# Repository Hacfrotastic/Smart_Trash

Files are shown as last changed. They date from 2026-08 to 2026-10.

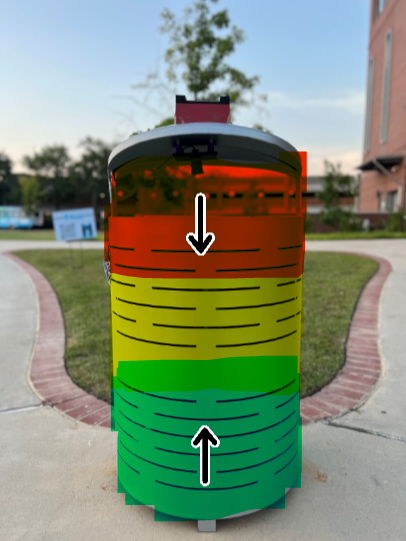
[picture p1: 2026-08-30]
Images/ST_Trash_LEVELS.png

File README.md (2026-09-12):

# Smart_Trash

## Intro

Smart trash is autonomous monitoring system bult to measure the levels in a trash cans. Once measurements are taken the device then sends them to grafana where they can be remotely monitored. This project was started to help give facilities and matinence more insight into how trash is disposed of on their campus. With levels constantly being monitered staff can see when each trash can need to be changed rather then relying on a scheduele.

## Latest Versions
 Code   - 
 Model  - *Fusion will not let me export rn.
 PCB    - 

## Previous contributers
- Hacfrotastic 
- Cameron Cuningham <- Spell check...

## Next Steps - We got this [on] the bag

April 15th 2026 we deployed the device in a trash can that does not get much traffic. On this day (August 30th 2026) it is still sending data with 6% battery life remaining (and 3.67 V for those interested). For a largew duration of the sensors deployement it was reading 85% full. I suspect these reading to be false and instead be the trash bag fluffed up by the air. I thought I solved this issue by adding a "bag flag" but apparently not....

 Additionally the reading value recently dropped to 0. I assume this is just a result of the battery dying

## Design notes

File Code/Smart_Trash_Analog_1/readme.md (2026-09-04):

# Smart_Trash Analog 

This is where it all started (kinda), so let's run through how it works.

## Setup()

Here we do 3 things. 
- set up our variable
- Establish some particle functions (see more in function section)
- configure sleep settings (config.mode)

## Loop()

Meat and potatoes time!!!

This is your typical analog readings code. 
- Get 10 readings from the ultrasonic sensor
    + We are working with 3.3V logic
    + The Borons ADC is 4096 bits
    + This Maxbotic sensors conversion formula is  3.2 cm per mV
    My code looks a little wrong to me, I believe in the code I'm using just volts in the formula (Needs Testing)
- Average readings 
- Calculate status based on reading
    + This started out as a discrete status, some may even say it was quantized. 1=Empty 2=halfway 3=full that is what you see on the first line of each if statement commented out.
    + Eventually we moved status to be a percent calculation with the formula in the second line. The formula takes the reading and divides it by the known max of the trashcan (70cm) while multiplying that number by 100 so it mimics a percent. Lastly subracting that number from 100 since the distance reading is the inverse of how full the trash can is. Cool right. 
- If status changes publish the status
    + The snprintf statement make the string; Particle.publish then sends it.

## Functions 
Lets go ahead and describe what each function does

### Debug 

 Expected input : Leave blank, input does not matter
 This runs the basic reading cycle and returns what ever status was reported

 ### Bedtime

 Expected input : Leave blank, input does not matter
 Forces the sensor to go to bed. The sleep time is hardcoded and set by the config.mode statement in setup()

 ### Battery_Rep
 
 Expected input : Leave blank, input does not matter
 This ones a little weird and a relic of me not knowiung how to do some things, but I'll leve it how it is so the reader can judge me. 
 First the board gets the percent of battery charge (ex. 100 -> 100% -> full charge). Then it reads the batteries voltage. Both of these readings are read using the Particle Borons built in "FuelGauge" functions that I have instatiated at the top of the code file. 
 To return both of the numbers in the same function, SOMONE had the "brilliant idea" of shifting the battery percent up by 1000 and adding the voltage to that. Example, battery percent = 83 Voltage = 3.7 makes the reported value 83003.7. Weird but it kinda works... 
 However,
  A) having two seperate published just seems better 
  B) THE INT CUTS THE DECIMAL OFF!!! I mean what the point of that kind of reading anyway. 3.7 drops to 3, so when you have full charge ~3.9V on my battery the function reads 4 and when you get low, hell even DEAD, ~3.5 it drops it to, you'll never guess 3!!!!!
  (Or new me is wrong and old me is better at coding, which is possible. Test it and find out)

  ### Function Graveyard

  There are some commented out functions I put in there with hipes of expanding the code to store GPS cords. ,but I never around to it. I'll leave them in there though to inspire.

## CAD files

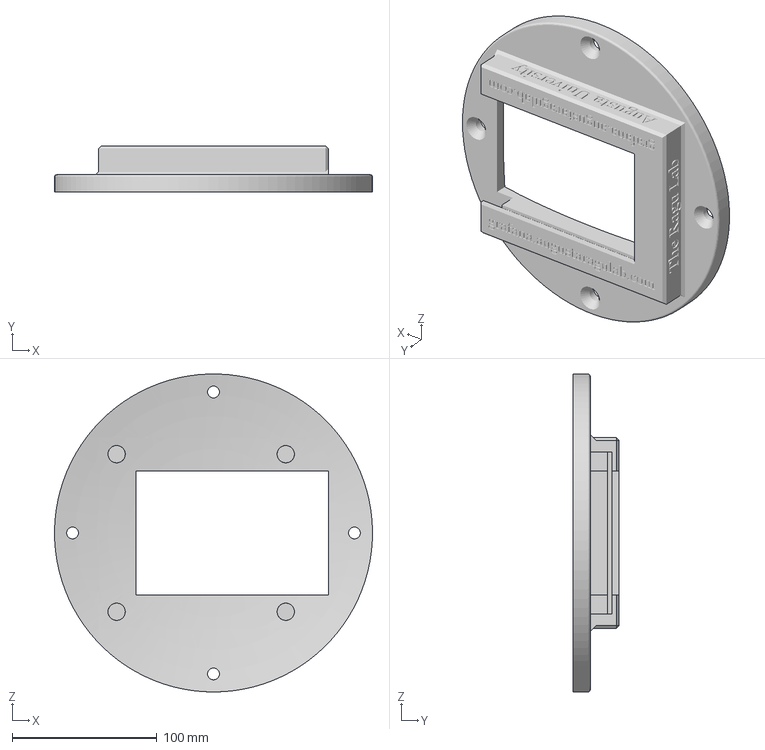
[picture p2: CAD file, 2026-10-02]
Design/CAD_Files/New_trash_Lid.3mf
220.0 x 32.1 x 219.9 mm

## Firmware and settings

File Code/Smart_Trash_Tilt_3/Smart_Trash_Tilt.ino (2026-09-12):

// This #include statement was automatically added by the Particle IDE

// Include Particle Device OS APIs
#include "Particle.h"
char buf[255];
int aReading;
int status; 
int nowDis;             //distance for avg
int stateOfCharge;      //for fuel gauge battery monitoring 
int batteryVoltage;     //^^
int report;
FuelGauge fuel;         
int readingPin = A0;    //Analog pin for reading distance
int powerPin = D13;     // pin for powering sensor (poor mans MosFet)
int tilt = A1;          //For tracking when the bag gets changed
bool isAwake;           //reports if the sensor is awake (currently it wakes up and stays after the noon report)
int numSamp = 25;       //Number of times the sensor will raje a reading before averaging
float cmDis = 0;        //
String myDev;
//Required constructor to remember device name.

// Let Device OS manage the connection to the Particle Cloud
SYSTEM_MODE(AUTOMATIC);

// Show system, cloud connectivity, and application logs over USB
// View logs with CLI using 'particle serial monitor --follow'
SerialLogHandler logHandler(LOG_LEVEL_INFO);
SystemSleepConfiguration config;

int EEPUT(String x)             // Functions for storing the name of the device in EEPROM
{
    //Get rid of spaces in the string
    for(int ii = 0; ii<x.length(); ii++)
    {
        if(x[ii]== ' ')
        {
            x[ii] = '_';
        }
    }
    //put the string in EEPROM
    EEPROM.put(1, x.length());
    for(int ii = 0; ii < x.length(); ii++)
    {
        EEPROM.put((ii + 2),x[ii]);
    }
    System.reset();
    return 1;
}

char* EEGET()                //Gets Device name from EEPROM
{
    if(EEPROM.read(1) != 0xFFFF) //if the memory is not empty, read it
    {
        
        int bytes2Read = EEPROM.read(1);
        static char dev_Name[100] = " "; 
        for(int ii = 0; ii<bytes2Read; ii++)
        {
         dev_Name[ii] = EEPROM.read((ii + 2));
        }
        return dev_Name; 
    }
    
    return "ERROR";
}

void SetBagFlag(bool state)
{
    if (state == 1)
    {
        EEPROM.put(201, "1");    //Flag on
    }
    else if(state == 0)
    {
        EEPROM.put(201,"0");     //Flag off
    }
    delay(1000);                 //Delay because I do not trust things 
    System.reset();              //Reset it for EEPROM to register
}

byte GetBoolFlag()
{
    byte state = EEPROM.read(201);
    return state;
}
// setup() runs once, when the device is first turned on
void setup() 
{
    Time.zone(-4);
    myDev = EEGET(); 
    while(!Particle.connected() || myDev == "ERROR") //Wait for board to connect or recieve name.
    {
        //wait for boron board to connect to cell
    }
    pinMode(readingPin, INPUT);
    pinMode(powerPin, OUTPUT);
    Particle.variable("Sensor Awake", isAwake);
    Particle.function("Measure Percent Full",debug);
    config.mode(SystemSleepMode::ULTRA_LOW_POWER).duration(60min); 
    Particle.function("Bedtime",bedtime);
    Particle.function("Set Name", EEPUT);
    Serial.begin(9600);
    
    //Setup required to retain name.
}

// loop() runs over and over again, as quickly as it can execute.
void loop() 
{
 /*
 Problem: The sensor sometimes reported 0 as a measurement when there were items in the trash can
 
 Fix:     I added a for loop that loops 2 times if and only if the reading reported is 0, this way
          the ultrasonic will double check all reports of 0s but can still publish 0 if the can is 
          actually empty 
          Also upped the amount of samples taken (10 -> 50)
 */
    
    //give a five minute delay so the sensor can retrieve its name 
    
 
  digitalWrite(powerPin, HIGH);  //turn on sensor through GPIO pin so it is not drainging the battery
  delay(30000);
  float avg;
  for(int ii=0; ii<numSamp ; ii++)
  {
     int aReading = analogRead(readingPin);
     float volts = (aReading*3.3)/4096;
     float cmDis = volts/0.0032;
     avg += cmDis; 
     Serial.print("Cm: ");
     Serial.print(cmDis);
     Serial.print("Avg: ");
     Serial.println(avg);
     delay(1000);
     
  }
  avg = avg/numSamp;
  int status = 100 - (((avg-15)/70)*100);  
  //filter status
  if (status > 100)
  {
      status = 100;
  }
  else if (status < 0)
  {
      status = 0;
  }
  
  Serial.println(status);
  //set the bag ch
  //Bag check code
  char bag = GetBoolFlag();                 //grab bag state from EEPROM
  if(bag =='1')                             //The tilt ball has fired and sensed that the trash has been changed
  {
      if(status >= 75)                      //It was just changed and got a full reading, this must be bag
      {
        status = 0;
      }
      else                                  //we are not seeing bag so lets reset the bag flag and not adjust the reading
      {
        SetBagFlag(0);                      //set the bag flag to 0 in EEPROM
      }
      
  }
    
    //Use for discord integration
    float voltage = fuel.getVCell();
    stateOfCharge = fuel.getNormalizedSoC();
    char* myDev = EEGET();
    //Under construction  DeviceNameHelperRetained::instance().getName()
    snprintf(buf, sizeof(buf), "{\"DeviceName\":\"%s\", \"PoC\": %d, \"BatteryVolts\": %.2f,\"TrashPercent\": %d, \"Bag\": %d}", myDev, stateOfCharge, voltage, status, bag);   //convert/save the data
    delay(100);
    Particle.publish("TashStop", buf, PRIVATE);          //publish battery data
   // digitalWrite(powerPin, LOW);
    delay(10000);
    Particle.publishVitals();
    delay(10000);
   // Serial.println(buf);
   SystemSleepResult result;
   
   if((Time.hour() <= 2) && (Time.hour() >= 0))  //  so this is midnight to 2 am have it sleep till morning
    {
        config.mode(SystemSleepMode::ULTRA_LOW_POWER).duration(6h).analog(tilt, 2000, AnalogInterruptMode::ABOVE);
        digitalWrite(powerPin, LOW);
        result = System.sleep(config);
    }
    else if(Time.hour() == 1)
    {
        isAwake = true;
        digitalWrite(powerPin, LOW);
        delay(3600000); //delay an hour and then go again
        //Stay awake for updates
        isAwake = false;
    }
    else
    {
        config.mode(SystemSleepMode::ULTRA_LOW_POWER).duration(60min).analog(tilt, 2000, AnalogInterruptMode::ABOVE);
        digitalWrite(powerPin, LOW);
        result = System.sleep(config);
    }
    //The tilt ball switch went off AKA trash got changed
    if (result.wakeupReason() == SystemSleepWakeupReason::BY_LPCOMP) 
    {
        SetBagFlag(1); //log that we may be seeing bag now
    }
  // Waken by pin 
    
    //delay(120000000);                               //update 2 minutes
    
    // Particle.publish("dmessage", "The status has changed")
}

int debug(String cmd)
{ 
    cmDis = 0;
    for(int ii = 0; ii<10; ii++)
  {
    aReading = analogRead(A0);
    float volts = aReading*3300.0/4095.0; // convert 
    cmDis += volts/3.2; 
    delay(1000);
  }
  cmDis = cmDis/10; //avg reading 
  //cmDis = 100 -((cmDis*100)/70);// make into percent
  return cmDis;
}

int bedtime(String cmd)
{
    System.sleep(config);
    //delay(6000000);
    return 1;
}

////////////////////////////
int Battery_Rep(String cmd)
{
   // stateOfCharge = (fuel.getNormalizedSoC() * 1000);
    batteryVoltage = (fuel.getVCell()*1000);
    return stateOfCharge + batteryVoltage;
}

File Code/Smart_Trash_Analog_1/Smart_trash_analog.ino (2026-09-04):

// Include Particle Device OS APIs
//This is for a Particle board. To use, copy into the Particle's web IDE or create a project file via VScode Particle workbench
//and put copy code to there

#include "Particle.h"

char buf[50];
int aReading;
float cmDis;
int oldStatus;
int status; 
int nowDis; //distance for avg
int lat;
int lon;
int stateOfCharge;      //for fuel gauge battery monitoring 
int batteryVoltage;     //^^
int report;
FuelGauge fuel;

// Let Device OS manage the connection to the Particle Cloud
SYSTEM_MODE(AUTOMATIC);

// Show system, cloud connectivity, and application logs over USB
// View logs with CLI using 'particle serial monitor --follow'
SerialLogHandler logHandler(LOG_LEVEL_INFO);
SystemSleepConfiguration config;
// setup() runs once, when the device is first turned on
void setup() 
{
    pinMode(A0, INPUT);
    config.mode(SystemSleepMode::ULTRA_LOW_POWER).duration(28800000); 
    Particle.function("Debug",debug);
    Particle.function("Bedtime",bedtime);
    Particle.function("Battery_Rep",Battery_Rep );
    //Particle.function("SetLat",SetLat);
    //Particle.function("Good", Good);
    //Particle.function("SetLon",SetLon);
    
  // Put initialization like pinMode and begin functions here
 
}

// loop() runs over and over again, as quickly as it can execute.
void loop() {
    cmDis = 0;
 for(int ii = 0; ii<10; ii++)
  {
    aReading = analogRead(A0);
    float volts = (aReading*3.3)/4095.0; // convert 
    cmDis += (volts/3.2);                //Converting Volts to millamerter
    delay(2000);
  }
                  // data sheet stuff
  //Serial.println(cmDis);
  cmDis = cmDis/10;
  if(cmDis>60)
  {
    //status = 1;
    status = 100 -((cmDis*100)/70);
    //Serial.println("empty");
  }
  else if(cmDis>30)
  {
      //status = 2;
      status = 100 -((cmDis*100)/70);
      //Serial.println("middle");
  }
  else
  {
      //status = 3;
      status = 100 -((cmDis*100)/70);
     // Serial.println("yikes");
  }
  
  
  if(status != oldStatus)
  {
    
    snprintf(buf, sizeof(buf), "%d Raw: %d", status, cmDis);   //convert/save the data
    Particle.publish("nrStatus", buf, PRIVATE);   //publish
   // Serial.println(buf);
    
    //System.sleep(SLEEP_MODE_DEEP, 60);
    delay(60000);                               //update long time
    // Particle.publish("dmessage", "The status has changed")
    //delay(10000000);
  }
  else
  {
      delay(1000);
  }
  oldStatus = status;
  //delay(1000);
    

    //snprintf(buf, sizeof(buf), "%d", cmDis);  //convert the data
    //Particle.publish("status", buf, PRIVATE); //publish

}

int debug(String cmd)
{
    cmDis=0;
    for(int ii = 0; ii<10; ii++)
  {
    aReading = analogRead(A0);
    float volts = aReading*3300.0/4095.0; // convert 
    cmDis += volts/3.2; 
    delay(2000);
  }
  cmDis = cmDis/10;
  return cmDis;
}

int bedtime(String cmd)
{
    System.sleep(config);
    delay(60000);
    return 1;
}

int Battery_Rep(String cmd)                             //I do not think this is a good way to do this btw 
{
    stateOfCharge = (fuel.getNormalizedSoC() * 1000);   //I believe these return floats
    batteryVoltage = (fuel.getVCell());                 //which is important cause we can only return int 
    return stateOfCharge + batteryVoltage;              //but since are variables are ints it should be okay you just loose some precision
}

//Relics of a vision I did not finish
/*
int SetLat(String cmd)
{
    lat = cmd.toInt();
    return 1;
}

int SetLon(String cmd)
{
    lon = cmd.toInt();
    return 1;
}

int Good(String cmd)
{
    return 1;
}
*/

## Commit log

2026-10-02 Add files via upload
    This is the lid of the trash now I have to find the bottom....
    [New_trash_Lid.3mf]
2026-10-14 Added the bottom of the lid CAD File
